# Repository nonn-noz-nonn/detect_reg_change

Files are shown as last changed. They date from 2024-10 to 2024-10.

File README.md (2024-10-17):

# 変動する抵抗値の観測

## 概要

- 対象のArduino : Arduino Uno Rev3
- 対象の抵抗値 : 0ohm - 500kohm
    - 電圧変換した抵抗値を0-1023 (10bit) の値として取得します．
- kohmオーダの抵抗値であれば±20dB程度の変動は取得できます．
    - ※ 取得した値の絶対値と精度は考慮していません．
- 下記の項目をシリアルターミナル上で設定できます．
    - 取得する値の下限
    - 取得する値の上限
    - LED点灯の閾値
    - LED点灯の論理
    - 1次LPFの係数
    - 取得間隔(目安)

※ 設定値の範囲や設定方法はArduinoスケッチをご覧ください．

## ソフトウェアのバージョン

作成に用いたソフトウェアのバージョンは次の通りです．

| ソフト名 | バージョン |
| ---- | ---- |
| Arduino IDE | 1.8.19 |
| KiCad | 6.0.2 |

## 注意

本リポジトリのコンテンツ (回路図，BOM，KiCad関連ファイル，Arduinoスケッチ) を流用，応用することは自由ですが，流用・応用した結果生じた問題・障害・損害について，作者 (nonn_noz_nonn (nonn-noz-nonn) ) は一切の責任を負いません．

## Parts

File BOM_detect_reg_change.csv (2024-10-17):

No. | Reference | Part number | Characteristic | Manufacturer | Description | Qty.
1 | C1 | 865080642006 | CAN - SMD | Würth Elektronik | CAP ALUM 10UF 20% 50V SMD | 1 | https://www.digikey.jp/ja/products/detail/w%C3%BCrth-elektronik/865080642006/5728046
2 | C2 | C1608X7R1H104K080AA | 0603 (1608 Metric) | TDK Corporation | CAP CER 0.1UF 50V X7R 0603 | 1 | https://www.digikey.jp/ja/products/detail/tdk-corporation/C1608X7R1H104K080AA/513811
3 | C3 | C1608C0G1H471J080AA | 0603 (1608 Metric) | TDK Corporation | CAP CER 470PF 50V C0G 0603 | 1 | https://www.digikey.jp/ja/products/detail/tdk-corporation/C1608C0G1H471J080AA/513775
4 | R1 | SG73P1JTTD1004F | 0603 (1608 Metric) | KOA Speer Electronics | RES 1M OHM 1% 1/3W 0603 | 1 | https://www.digikey.jp/ja/products/detail/koa-speer-electronics-inc/SG73P1JTTD1004F/10188365
5 | R2 R5 | SG73P1JTTD1001F | 0603 (1608 Metric) | KOA Speer Electronics | RES 1K OHM 1% 1/3W 0603 | 2 | https://www.digikey.jp/ja/products/detail/koa-speer-electronics-inc/SG73P1JTTD1001F/10188084
6 | R3 | SG73P1JTTD1002F | 0603 (1608 Metric) | KOA Speer Electronics | RES 10K OHM 1% 1/3W 0603 | 1 | https://www.digikey.jp/ja/products/detail/koa-speer-electronics-inc/SG73P1JTTD1002F/10188408
7 | R4 | SG73P1JTTD2002F | 0603 (1608 Metric) | KOA Speer Electronics | RES 20K OHM 1% 1/3W 0603 | 1 | https://www.digikey.jp/ja/products/detail/koa-speer-electronics-inc/SG73P1JTTD2002F/10188044
8 | R6 | SG73P1JTTD1003F | 0603 (1608 Metric) | KOA Speer Electronics | RES 100K OHM 1% 1/3W 0603 | 1 | https://www.digikey.jp/ja/products/detail/koa-speer-electronics-inc/SG73P1JTTD1003F/10188341
9 | R7 | RK73B1JTTD621J | 0603 (1608 Metric) | KOA Speer Electronics | RES 620 OHM 5% 1/8W 0603 | 1 | https://www.digikey.jp/ja/products/detail/koa-speer-electronics-inc/RK73B1JTTD621J/9844798
10 | U1 | AD8506ARMZ | 8-TSSOP | Analog Devices Inc. | IC CMOS 2 CIRCUIT 8MSOP | 1 | https://www.digikey.jp/ja/products/detail/analog-devices-inc/AD8506ARMZ/1971603
11 | Q1 | IRLML6344TRPBF | SOT-23-3 | Infineon Technologies | MOSFET N-CH 30V 5A MICRO3/SOT23 | 1 | https://www.digikey.jp/ja/products/detail/infineon-technologies/IRLML6344TRPBF/2538152
12 | D1 | ESDA5-1F4 | 0201 (0603 Metric) | STMicroelectronics | TVS DIODE 5.5VWM 9VC 0201 | 1 | https://www.digikey.jp/ja/products/detail/stmicroelectronics/ESDA5-1F4/7313246
13 | D2 | XZMDK53W-1 | 0603 (1608 Metric) | SunLED | LED RED CLEAR CHIP SMD | 1 | https://www.digikey.jp/ja/products/detail/sunled/XZMDK53W-1/4745950
14 | CN1 | 691210910002 | 2.54mm pitch Through-Hole | Würth Elektronik | TERM BLOCK 2P HORIZON 2.54MM PCB | 1 | https://www.digikey.jp/ja/products/detail/w%C3%BCrth-elektronik/691210910002/10668428
15 | P1 P2 P3 P4 | 85 | 2.54mm pitch Through-Hole | Adafruit Industries LLC | STACKING HEADER ARDUINO SHIELD | 1 | https://www.digikey.jp/ja/products/detail/adafruit-industries-llc/85/5154649

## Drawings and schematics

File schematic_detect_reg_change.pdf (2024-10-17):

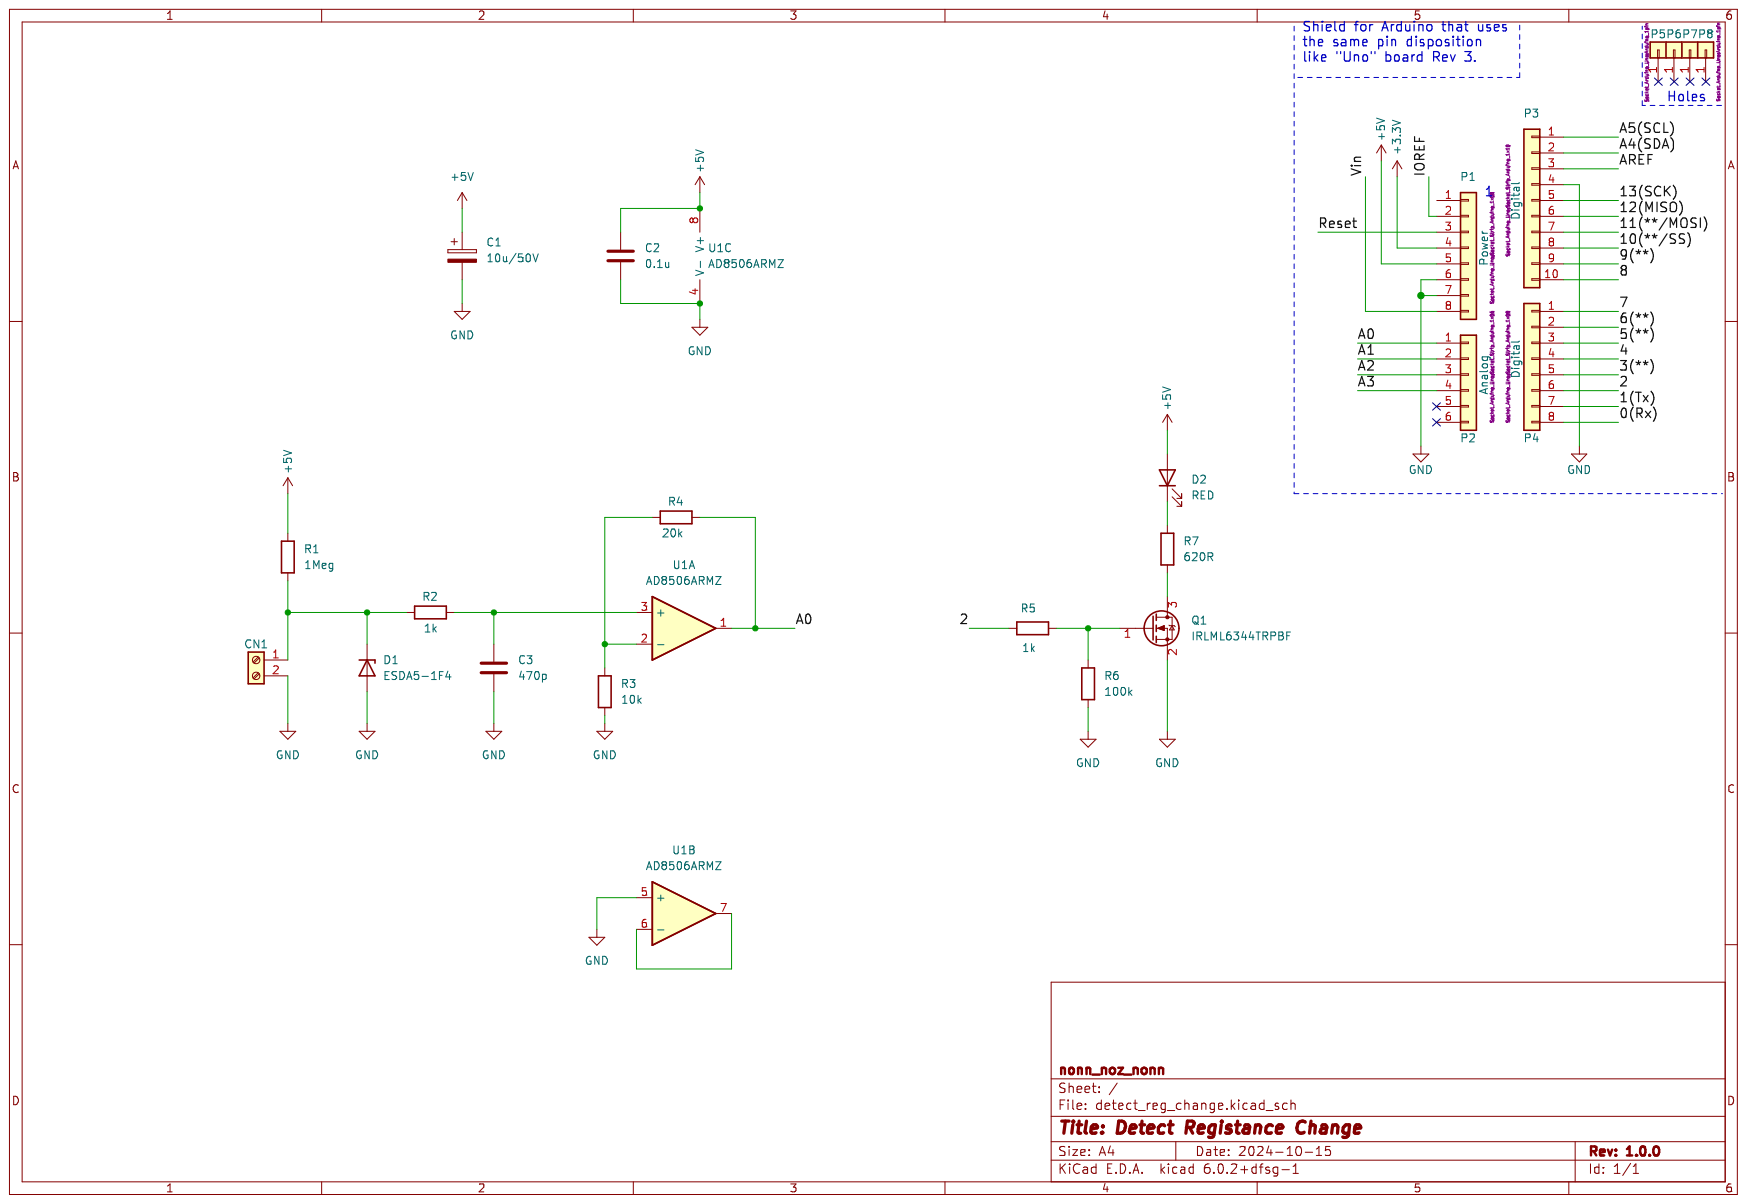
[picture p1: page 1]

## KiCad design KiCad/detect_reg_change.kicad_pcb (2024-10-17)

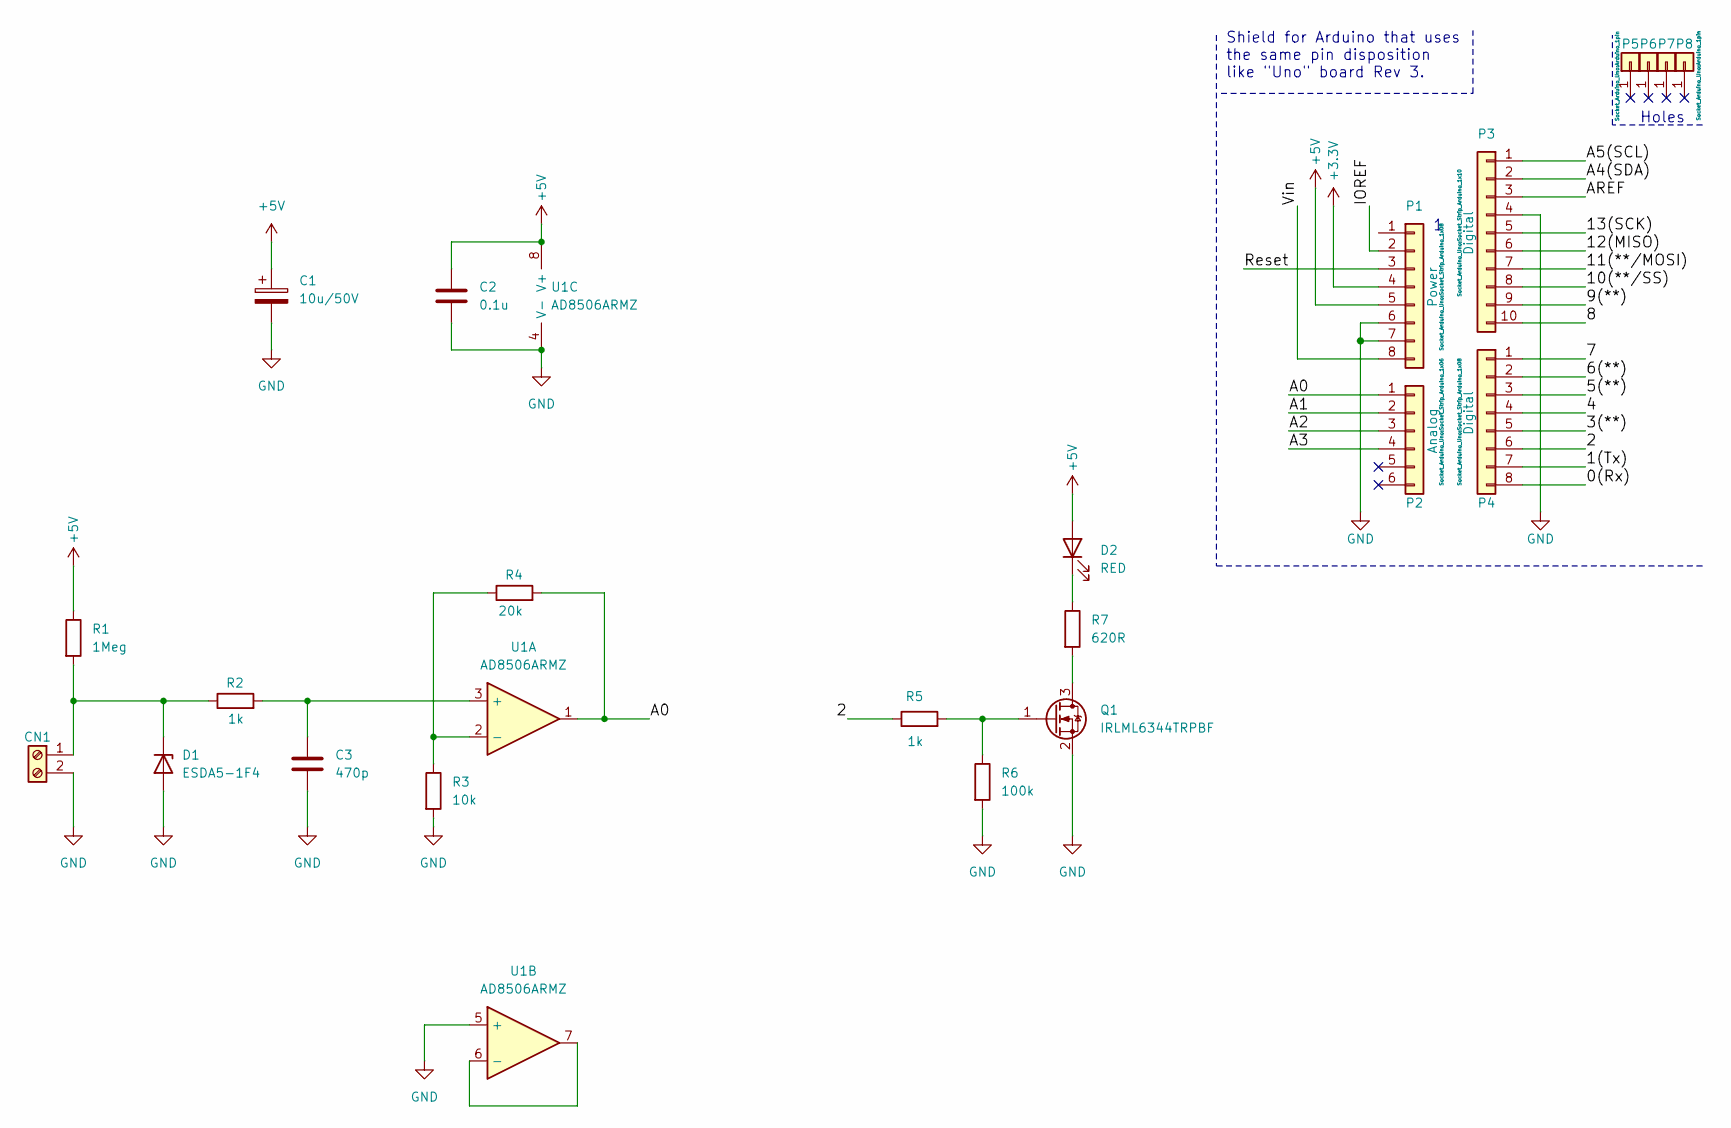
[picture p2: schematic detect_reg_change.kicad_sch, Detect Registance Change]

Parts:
C1: 10u/50V; CP_Elec_5x5.4
C2: 0.1u; C_0603_1608Metric
C3: 470p; C_0603_1608Metric
CN1: Screw_Terminal_01x02; PinSocket_1x02_P2.54mm_Vertical
D1: ESDA5-1F4; D_0201_0603Metric
D2: RED; LED_0603_1608Metric
P1: Power; Socket_Strip_Arduino_1x08
P2: Analog; Socket_Strip_Arduino_1x06
P3: Digital; Socket_Strip_Arduino_1x10
P4: Digital; Socket_Strip_Arduino_1x08
P5, P6, P7, P8: CONN_01X01; Arduino_1pin
Q1: IRLML6344TRPBF; SOT-23
R1: 1Meg; R_0603_1608Metric
R2, R5: 1k; R_0603_1608Metric
R3: 10k; R_0603_1608Metric
R4: 20k; R_0603_1608Metric
R6: 100k; R_0603_1608Metric
R7: 620R; R_0603_1608Metric
U1: AD8506ARMZ; TSSOP-8_3x3mm_P0.65mm

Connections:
+3V3: P1.4
+5V: C1.1, C2.1, D2.2 (A), P1.5, R1.1, U1.8 (V+)
/0(Rx): P4.8
/1(Tx): P4.7
/2: P4.6, R5.1
/3(**): P4.5
/4: P4.4
/5(**): P4.3
/6(**): P4.2
/7: P4.1
/8: P3.10
/9(**): P3.9
/10(**/SS): P3.8
/11(**/MOSI): P3.7
/12(MISO): P3.6
/13(SCK): P3.5
/A0: P2.1, R4.2, U1.1
/A1: P2.2
/A2: P2.3
/A3: P2.4
/A4(SDA): P3.2
/A5(SCL): P3.1
/AREF: P3.3
/IOREF: P1.2
/Reset: P1.3
/Vin: P1.8
GND: C1.2, C2.2, C3.2, CN1.2, D1.2 (A), P1.6, P1.7, P3.4, Q1.2 (S), R3.2, R6.2, U1.4 (V-), U1.5 (+)
unnamed: C3.1, R2.2, U1.3 (+)
unnamed: CN1.1, D1.1 (K), R1.2, R2.1
unnamed: D2.1 (K), R7.1
unnamed: Q1.1 (G), R5.2, R6.1
unnamed: Q1.3 (D), R7.2
unnamed: R3.1, R4.1, U1.2 (-)
unnamed: U1.6 (-), U1.7

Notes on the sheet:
Holes
Shield for Arduino that uses the same pin disposition like "Uno" board Rev 3.

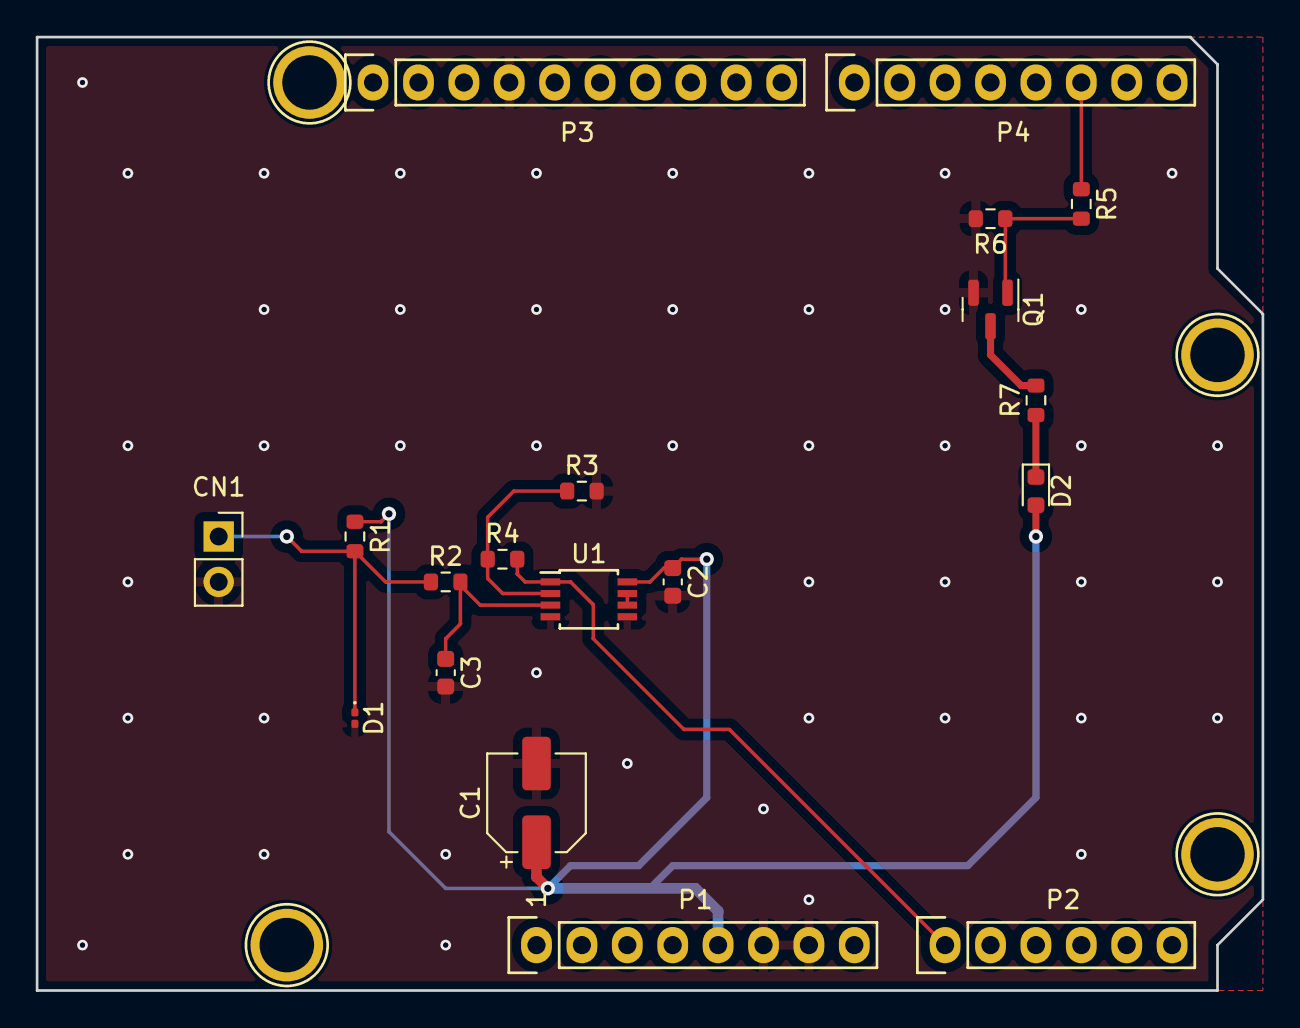
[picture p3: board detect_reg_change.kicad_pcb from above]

Board: 2 copper layers, 68.6 x 53.3 mm, 23 parts (0 on the bottom side), 11 nets.

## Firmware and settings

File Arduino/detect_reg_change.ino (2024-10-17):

int ADIN_PIN = 0;
int LED_PIN = 2;

typedef enum STATE_T {
    STOP = 0,
    RUN,
} STATE;

typedef struct PARAM_T {
    uint16_t th_btm;
    uint16_t th_top;
    uint16_t th_led;
    uint8_t led_logic;
    float lpf_a0;
    unsigned long delay_ms;
} PARAM;

const int COMMAND_QUIT = 'q';
const int COMMAND_START = 's';
const int COMMAND_READ = 'r';
const int COMMAND_WRITE = 'w';

void recv_command(STATE *sts, PARAM *prm);
void send_param(const PARAM *prm);
void recv_param(PARAM *prm);
bool delimit_str_recv(String str, char token[][16]);
void parse_token(const char token[][16], PARAM *prm);
void send_result(const PARAM *prm);

void setup() {
    // put your setup code here, to run once:
    pinMode(LED_PIN, OUTPUT);
    digitalWrite(LED_PIN, LOW);
    Serial.begin(9600);
    Serial.setTimeout(100);
}

void loop() {
    // put your main code here, to run repeatedly:
    static STATE state = STOP;
    static PARAM param = {0U, 1023U, 511U, 0U, 0.5f, 10UL};
    
    if ( Serial.available() > 0 ) {
        recv_command(&state, &param);
    }
    
    if ( RUN == state ) {
        send_result(&param);
    }
}

void recv_command(STATE *sts, PARAM *prm)
{
    int recv = Serial.read();
    if ( COMMAND_QUIT == recv ) {
        if ( RUN == *sts ) {
            digitalWrite(LED_PIN, LOW);
            *sts = STOP;
        }
    } else if ( COMMAND_START == recv ) {
        if ( STOP == *sts ) {
            *sts = RUN;
        }
    } else if ( COMMAND_READ == recv ) {
        if ( STOP == *sts ) {
            send_param(prm);
        }
    } else if ( COMMAND_WRITE == recv ) {
        if ( STOP == *sts ) {
            recv_param(prm);
        }
    }
    return;
}

void send_param(const PARAM *prm)
{
    String str_th_btm = String(prm->th_btm, DEC);
    String str_th_top = String(prm->th_top, DEC);
    String str_th_led = String(prm->th_led, DEC);
    String str_led_logic = String(prm->led_logic, DEC);
    String str_lpf_a0 = String(prm->lpf_a0, 3);
    String str_delay_ms = String(prm->delay_ms, DEC);
    String str_resp = String(str_th_btm + "," + 
                             str_th_top + "," + 
                             str_th_led + "," + 
                             str_led_logic + "," + 
                             str_lpf_a0 + "," + 
                             str_delay_ms);
    Serial.println(str_resp);
    return;
}

void recv_param(PARAM *prm)
{
    String str_recv = "";
    while ( 0 == str_recv.length() ) {
        str_recv = Serial.readString();
        str_recv.trim();
    }
    
    str_recv.replace(" ", "");
    
    char token[6][16];
    memset(token, '\0', sizeof(token));
    
    bool ret = delimit_str_recv(str_recv, token);
    if ( false == ret ) {
        goto EXIT;
    }
    
    parse_token(token, prm);
    
EXIT:
    return;
}

bool delimit_str_recv(String str, char token[][16])
{
    bool ret = false;
    
    char *str_ptr = (char *)(str.c_str()); 
    char *delim_ptr = NULL;
    uint8_t token_cnt = 0U;
    
    delim_ptr = strtok(str_ptr, ",");
    snprintf(token[token_cnt], 16, "%s", delim_ptr);
    token_cnt++;
    
    while ( NULL != delim_ptr && token_cnt < 6 ) {
        delim_ptr = strtok(NULL, ",");
        if ( NULL != delim_ptr ) {
            snprintf(token[token_cnt], 16, "%s", delim_ptr);
            token_cnt++;
        }
    }
    
    if ( 6 != token_cnt ) {
        Serial.println("E00: number of param invalid.");
        ret = false;
        goto EXIT;
    }
    ret = true;
    
EXIT:
    return ret;
}

void parse_token(const char token[][16], PARAM *prm)
{
    PARAM tmp_prm;
    memset(&tmp_prm, 0, sizeof(tmp_prm));
    
    unsigned long num = 0U;
    char *endptr = NULL;
    float fnum = 0.0f;
    
    num = strtoul(token[0], &endptr, 10);
    if ( '\0' != *endptr || num > 1023U ) {
        Serial.println("E01: threshold of bottom [0-1023] invalid.");
        goto EXIT;
    }
    tmp_prm.th_btm = (uint16_t)num;
    
    num = strtoul(token[1], &endptr, 10);
    if ( '\0' != *endptr || num > 1023U ) {
        Serial.println("E02: threshold of top [0-1023] invalid.");
        goto EXIT;
    }
    tmp_prm.th_top = (uint16_t)num;
    
    num = strtoul(token[2], &endptr, 10);
    if ( '\0' != *endptr || num > 1023U ) {
        Serial.println("E03: threshold of LED [0-1023] invalid.");
        goto EXIT;
    }
    tmp_prm.th_led = (uint16_t)num;
    
    num = strtoul(token[3], &endptr, 10);
    if ( '\0' != *endptr || num > 1U ) {
        Serial.println("E04: logic of LED [0-1] invalid.");
        goto EXIT;
    }
    tmp_prm.led_logic = (uint8_t)num;
    
    fnum = (float)strtod(token[4], &endptr);
    if ( '\0' != *endptr || fnum > 1.0f || fnum < 0.0f ) {
        Serial.println("E05: a0 of LPF [0.0-1.0] invalid.");
        goto EXIT;
    }
    tmp_prm.lpf_a0 = fnum;
    
    num = strtoul(token[5], &endptr, 10);
    if ( '\0' != *endptr ) {
        Serial.println("E06: delay time [msec] invalid.");
        goto EXIT;
    }
    tmp_prm.delay_ms = num;
    
    if ( tmp_prm.th_top <= tmp_prm.th_btm ) {
        Serial.println("E07: threshold of top must be larger than of bottom.");
        goto EXIT;
    }
    
    if ( tmp_prm.th_led < tmp_prm.th_btm || tmp_prm.th_led > tmp_prm.th_top ) {
        Serial.println("E08: threshold of led must be a value between of bottom and of top.");
        goto EXIT;
    }
    
    memcpy(prm, &tmp_prm, sizeof(tmp_prm));
EXIT:
    return;
}

void send_result(const PARAM *prm)
{
    uint16_t adc_val = analogRead(ADIN_PIN);
    
    static float y[2] = {0};
    y[1] = prm->lpf_a0 * y[0] + (1.0 - prm->lpf_a0) * adc_val;
    y[0] = y[1];
    uint16_t dout = (uint16_t)y[1];
    
    if ( dout < prm->th_btm ) {
        dout = prm->th_btm;
    } else if ( dout > prm->th_top ) {
        dout = prm->th_top;
    }
    
    if ( dout < prm->th_led ) {
        if ( 0U == prm->led_logic ) {
            digitalWrite(LED_PIN, HIGH);
        } else {
            digitalWrite(LED_PIN, LOW);
        }
    } else {
        if ( 0U == prm->led_logic ) {
            digitalWrite(LED_PIN, LOW);
        } else {
            digitalWrite(LED_PIN, HIGH);
        }
    }
    
    Serial.println(dout, DEC);
    
    delay(prm->delay_ms);
}

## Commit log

2024-10-17 add schematic file
    add image (pdf) file of schematic.
2024-10-17 add BOM file
    add csv file of BOM.
    [BOM_detect_reg_change.csv]
2024-10-17 add KiCad files
    add all the files about KiCad.
    [detect_reg_change.kicad_pcb, detect_reg_change.kicad_sch]
2024-10-17 add Arduino sketch
    add sketch (.ino) file for Arduino Uno.
